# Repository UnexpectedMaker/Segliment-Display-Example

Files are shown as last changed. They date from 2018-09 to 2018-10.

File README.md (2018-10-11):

# Segliment-Display

As promised, I have open sourced my version of the Segliment Display that I made as a joint project with David Watts

The repositry includes thw following folders

EAGLE - All Eagle CAD files (v9.2)

GERBERS - All gerber files

SEGLIMENT_DISPLAY_EXAMPLE - Example Arduino code

Plus there is a PDF Schematic and BOM

Here are some Affiliate & Non-Affiliate links to some of the parts I am using..

COB LED Filaments 

http://s.click.aliexpress.com/e/H0sUjrw

MCP23017SP2 GPIO Port Expander

https://www.aliexpress.com/item/10PCS-MCP23017-E-SP-DIP-28-MCP23017-16-Bit-I-O-Expander-with-I2C-Interface-IC/32866049803.html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

10k Network Resistor

http://s.click.aliexpress.com/e/cFmRmzUk

Enjoy!

# Buy me a coffee or back me on Patreon?
I love making and designing projects but sharing open source projects takes a lot of thought and time. I do it because I think it’s important to share knowledge and give back to the community like many have done before me.

If you find this project useful or want to see more open source projects like it, please consider buying me a coffee or backing me on Patreon to say thanks!

buymeacofee (https://www.buymeacoffee.com/YLVGbhJP0)


# Unexpected Maker
http://youtube.com/c/unexpectedmaker

http://twitter.com/unexpectedmaker

https://www.facebook.com/unexpectedmaker/

https://www.instagram.com/unexpectedmaker/

https://www.tindie.com/stores/seonr/

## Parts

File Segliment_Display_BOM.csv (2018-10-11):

Partlist exported from /Users/seon/Dropbox/EagleCAD/projects/Siglement Display/Siglement 2018-2/Segliment_Display.sch at 11/10/18 4:24 PM
Part   Value       Device                          Package               Description
C1     0.1uF       0.1UF-KIT-EZ-50V-20%            CAP-PTH-SMALL-KIT     0.1µF ceramic capacitors
C2     10uF        10UF-POLAR-RADIAL-2.5MM-25V-20% CPOL-RADIAL-2.5MM-5MM 10.0µF polarized capacitors
IC1    MCP23017SP2 MCP23017SP2                     DIL28-3-ROUND         hMCP23017SP2 GPIO Expander
IO_IN              CONN_041X04_NO_SILK             1X04_NO_SILK          0.254mm 4 pin header
IO_OUT             CONN_041X04_NO_SILK             1X04_NO_SILK          0.254mm 4 pin header
J1                 CONN_031X03_NO_SILK             1X03_NO_SILK        	 0.254mm 3 pin header
J2                 CONN_031X03_NO_SILK             1X03_NO_SILK          0.254mm 3 pin header
J3                 CONN_031X03_NO_SILK             1X03_NO_SILK          0.254mm 3 pin header
LED                LED3MM                          LED_3MM               3mm Yellow LED
LED1   1           LED28-30MMRAISED                RAISED                This is a filament LED
LED2   2           LED28-30MMRAISED                RAISED                This is a filament LED
LED3   3           LED28-30MMRAISED                RAISED                This is a filament LED
LED4   4           LED28-30MMRAISED                RAISED                This is a filament LED
LED5   5           LED28-30MMRAISED                RAISED                This is a filament LED
LED6   6           LED28-30MMRAISED                RAISED                This is a filament LED
LED7   7           LED28-30MMRAISED                RAISED                This is a filament LED
LED8   8           LED28-30MMRAISED                RAISED                This is a filament LED
LED9   9           LED28-30MMRAISED                RAISED                This is a filament LED
LED10  10          LED28-30MMRAISED                RAISED                This is a filament LED
LED11  11          LED28-30MMRAISED                RAISED                This is a filament LED
LED12  12          LED28-30MMRAISED                RAISED                This is a filament LED
LED13  13          LED28-30MMRAISED                RAISED                This is a filament LED
R1                 R-US_0207/7                     0207/7                100R
R2                 R-US_0207/7                     0207/7                100R
R3                 R-US_0207/7                     0207/7                100R
R4                 R-US_0207/7                     0207/7                100R
R5                 R-US_0207/7                     0207/7                100R
R6                 R-US_0207/7                     0207/7                100R
R7                 R-US_0207/7                     0207/7                100R
R8                 R-US_0207/7                     0207/7                100R
R9                 R-US_0207/7                     0207/7                100R
R10                R-US_0207/7                     0207/7                100R
R11                R-US_0207/7                     0207/7                100R
R12                R-US_0207/7                     0207/7                100R
R13                R-US_0207/7                     0207/7                100R
R14                R-US_0207/7                     0207/7                220R
RN                 RN05                            RN-6                  10K RESISTOR NETWORK

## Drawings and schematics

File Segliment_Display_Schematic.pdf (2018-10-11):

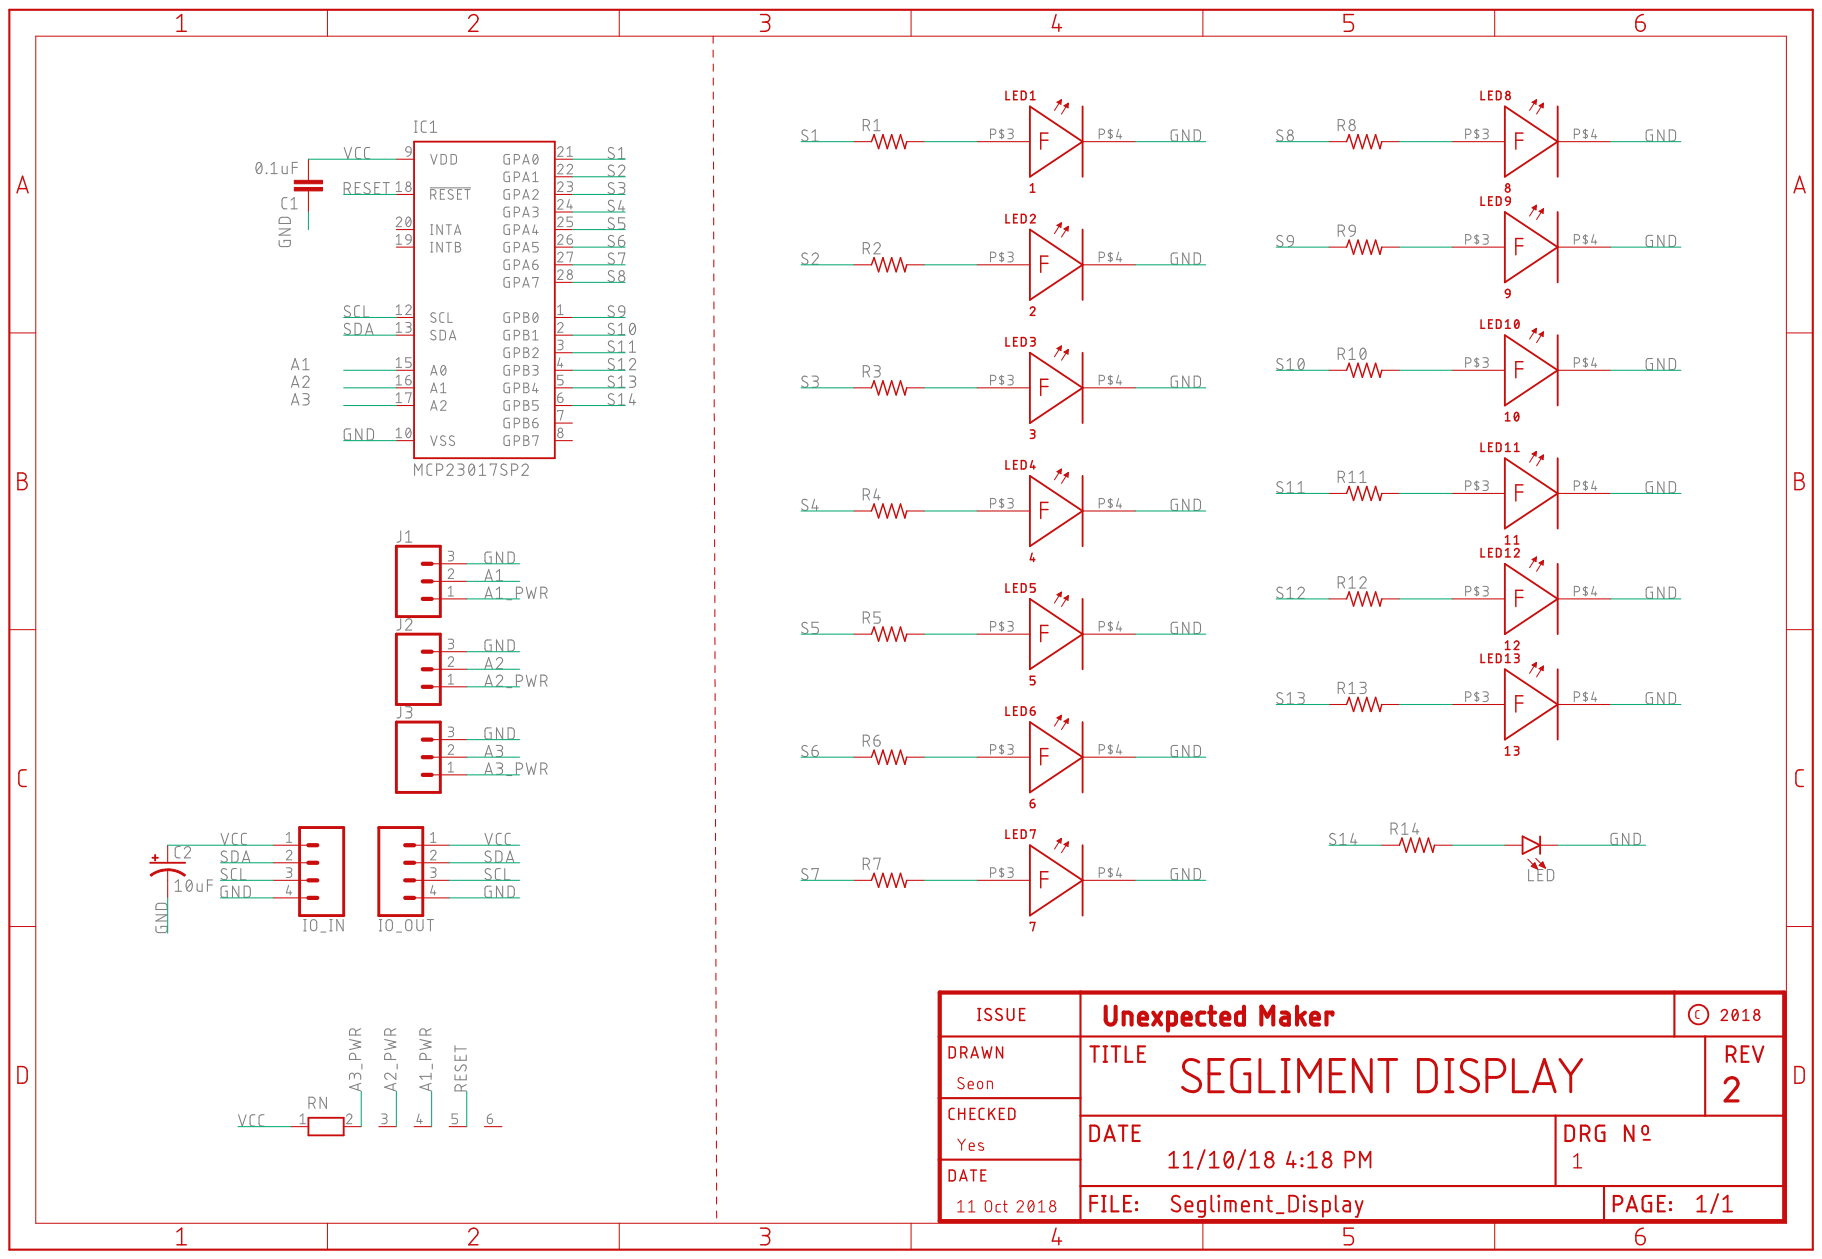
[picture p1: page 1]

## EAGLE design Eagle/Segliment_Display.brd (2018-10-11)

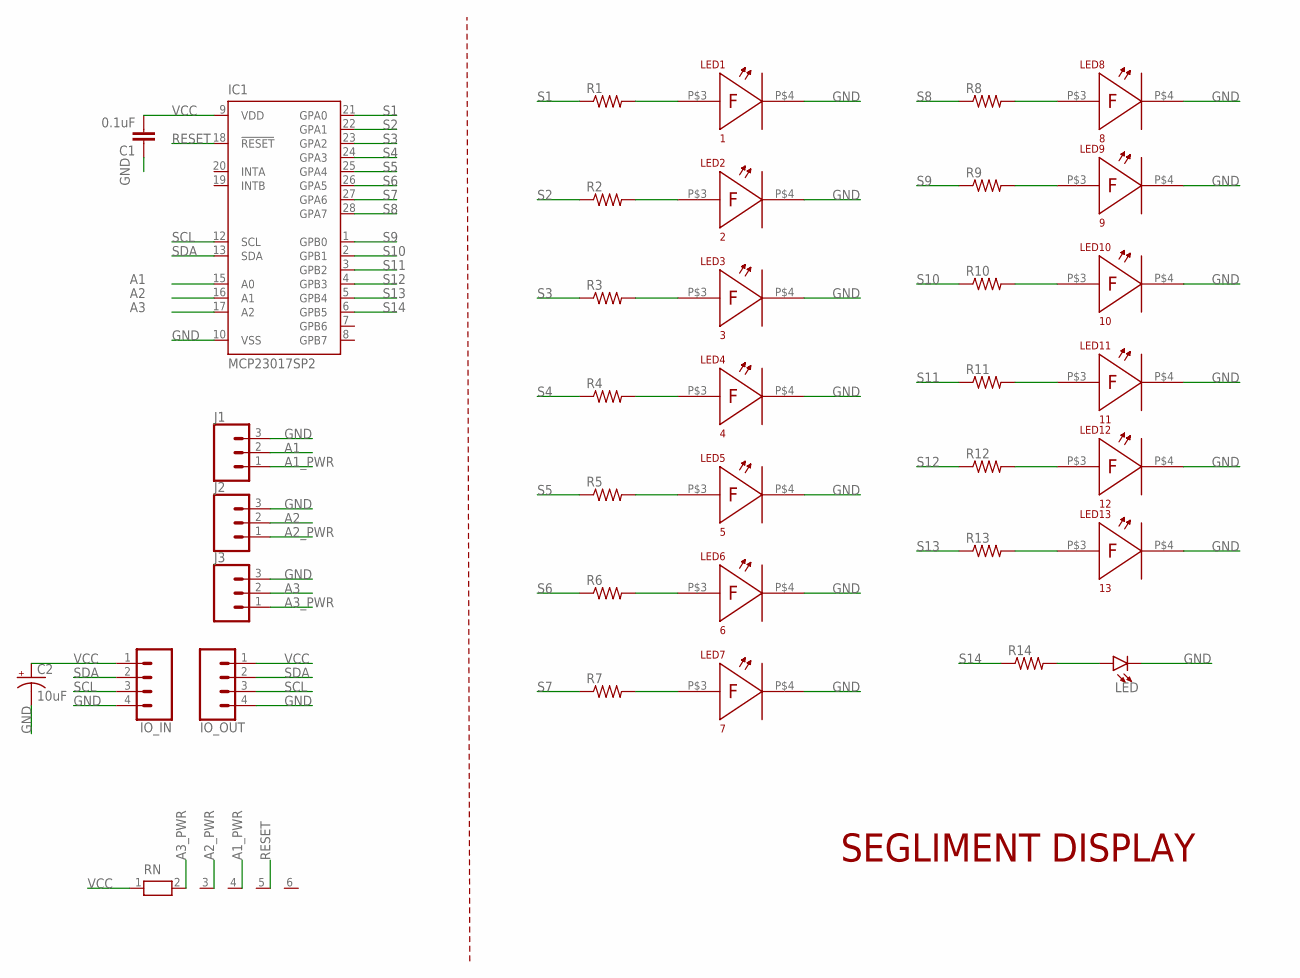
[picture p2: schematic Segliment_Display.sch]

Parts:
C1: 0.1uF; CAP-PTH-SMALL-KIT
C2: 10uF; CPOL-RADIAL-2.5MM-5MM
IC1: MCP23017SP2; DIL28-3-ROUND
IO_IN: CONN_041X04_NO_SILK; 1X04_NO_SILK
IO_OUT: CONN_041X04_NO_SILK; 1X04_NO_SILK
J1, J2, J3: CONN_031X03_NO_SILK; 1X03_NO_SILK
LED: LED3MM; LED_3MM
LED1: 1; RAISED
LED2: 2; RAISED
LED3: 3; RAISED
LED4: 4; RAISED
LED5: 5; RAISED
LED6: 6; RAISED
LED7: 7; RAISED
LED8: 8; RAISED
LED9: 9; RAISED
LED10: 10; RAISED
LED11: 11; RAISED
LED12: 12; RAISED
LED13: 13; RAISED
R1, R2, R3, R4, R5, R6, R7, R8, R9, R10, R11, R12, R13, R14: R-US_0207/7; 0207/7
RN: RN05; RN-6

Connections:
A1: IC1.15 (A0), J1.2
A1_PWR: J1.1, RN.4
A2: IC1.16 (A1), J2.2
A2_PWR: J2.1, RN.3
A3: IC1.17 (A2), J3.2
A3_PWR: J3.1, RN.2
GND: C1.1, C2.2 (-), IC1.10 (VSS), IO_IN.4, IO_OUT.4, J1.3, J2.3, J3.3, LED.K (C), LED1.P$4, LED2.P$4, LED3.P$4, LED4.P$4, LED5.P$4, LED6.P$4, LED7.P$4, LED8.P$4, LED9.P$4, LED10.P$4, LED11.P$4, LED12.P$4, LED13.P$4
unnamed: LED1.P$3, R1.2
unnamed: LED.A, R14.2
unnamed: LED2.P$3, R2.2
unnamed: LED3.P$3, R3.2
unnamed: LED4.P$3, R4.2
unnamed: LED5.P$3, R5.2
unnamed: LED6.P$3, R6.2
unnamed: LED7.P$3, R7.2
unnamed: LED8.P$3, R8.2
unnamed: LED9.P$3, R9.2
unnamed: LED10.P$3, R10.2
unnamed: LED11.P$3, R11.2
unnamed: LED12.P$3, R12.2
unnamed: LED13.P$3, R13.2
RESET: IC1.18 (!RESET), RN.5
S1: IC1.21 (GPA0), R1.1
S2: IC1.22 (GPA1), R2.1
S3: IC1.23 (GPA2), R3.1
S4: IC1.24 (GPA3), R4.1
S5: IC1.25 (GPA4), R5.1
S6: IC1.26 (GPA5), R6.1
S7: IC1.27 (GPA6), R7.1
S8: IC1.28 (GPA7), R8.1
S9: IC1.1 (GPB0), R9.1
S10: IC1.2 (GPB1), R10.1
S11: IC1.3 (GPB2), R11.1
S12: IC1.4 (GPB3), R12.1
S13: IC1.5 (GPB4), R13.1
S14: IC1.6 (GPB5), R14.1
SCL: IC1.12 (SCL), IO_IN.3, IO_OUT.3
SDA: IC1.13 (SDA), IO_IN.2, IO_OUT.2
VCC: C1.2, C2.1 (+), IC1.9 (VDD), IO_IN.1, IO_OUT.1, RN.1

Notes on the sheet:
SEGLIMENT DISPLAY

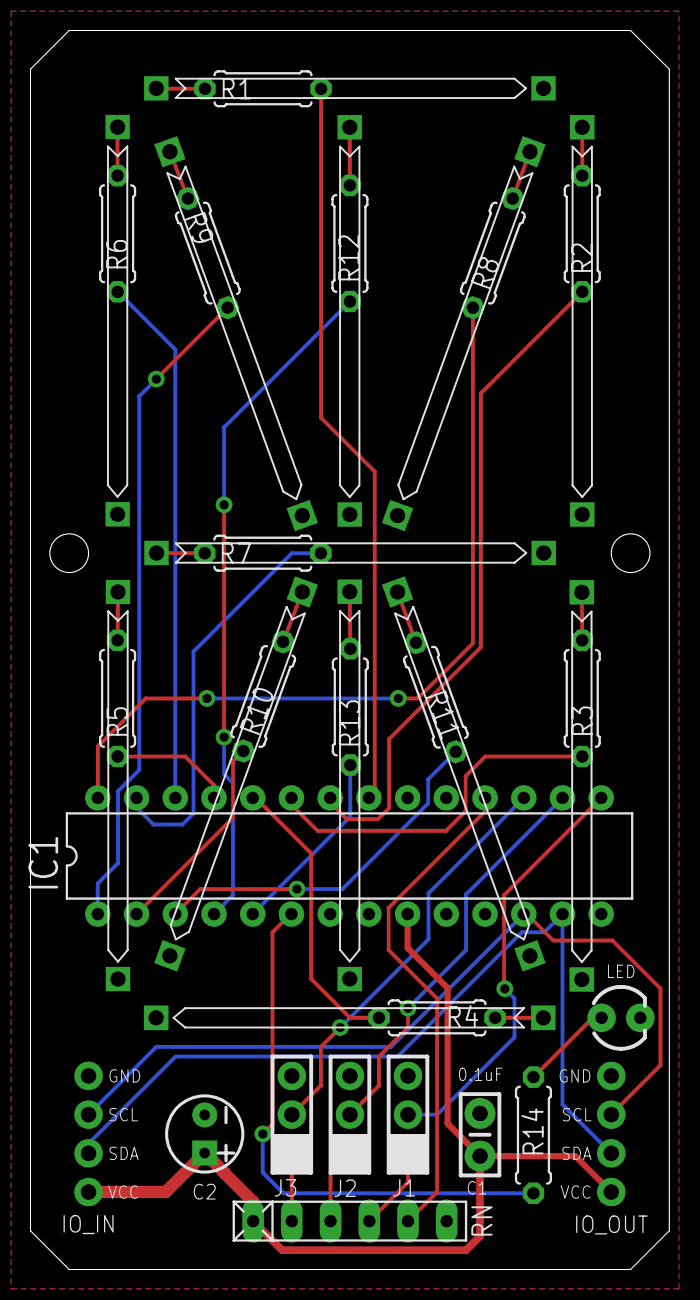
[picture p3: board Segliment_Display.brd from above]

Board: 2 copper layers, 41.9 x 81.3 mm, 37 parts (0 on the bottom side), 39 nets.

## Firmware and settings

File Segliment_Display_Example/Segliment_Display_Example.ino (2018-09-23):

// ---------------------------------------------------------------------------
// Created by Seon Rozenblum - seon@unexpectedmaker.com
// Copyright 2018 License: GNU GPL v3 http://www.gnu.org/licenses/gpl-3.0.html
//
// Required libraries
// Adafruit_MCP23017
// ---------------------------------------------------------------------------

#include <Wire.h>
#include "Adafruit_MCP23017.h"

typedef struct 
{
  char id;
  uint16_t leds;
} CharacterX;

// Available characters the segliment display can show            
const byte ARRAY_SIZE = 49;

CharacterX characters_led[ ARRAY_SIZE ] {
  { ' ', 0b0000000000000000 },
  { '0', 0b0000000000111111 }, 
  { '1', 0b0000000010000110 },
  { '2', 0b0000000001011011 },
  { '3', 0b0000000001001111 },
  { '4', 0b0000000001100110 },
  { '5', 0b0000000001101101 },
  { '6', 0b0000000001111100 },
  { '7', 0b0001000010000001 },
  { '8', 0b0000000001111111 },
  { '9', 0b0000000001100111 },
  { 'a', 0b0000000001110111 },
  { 'b', 0b0001100001001111 },
  { 'c', 0b0000000000111001 },
  { 'd', 0b0001100000001111 },
  { 'e', 0b0000000001111001 },
  { 'f', 0b0000000001110001 },
  { 'g', 0b0000010000111001 },
  { 'h', 0b0000000001110110 },
  { 'i', 0b0001100000001001 },
  { 'j', 0b0000000000011110 },
  {'k', 0b0000010010110000 },
  {'l', 0b0000000000111000},
  {'m', 0b0000000110110110},
  {'n', 0b0000010100110110},
  {'o', 0b0000000000111111},
  {'p', 0b0000000001110011},
  {'q', 0b0000010000111111},
  {'r', 0b0000010010110001},
  {'s', 0b0000000101001101},
  {'t', 0b0001100000000001},
  {'u', 0b0000000000111110},
  {'v', 0b0000001010110000},
  {'w', 0b0000011000110110},
  {'x', 0b0000011110000000},
  {'y', 0b0001000110000000},
  {'z', 0b0000001010001001},
  {'*', 0b0001111110000000},
  {'+', 0b0001100001000000},
  {'-', 0b0000000001000000},
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
};

// Create a reference for each display
Adafruit_MCP23017 mcp[1];
  
void setup()
{ 
  // Initialise each display with it's I2C address
  mcp[0].begin(1);      

  // Set each IO on the display to be outputs
  for ( int i = 0; i < 15; i++ )
    mcp[0].pinMode(i, OUTPUT);

  // clear the display
  ClearDisplay(0);

  // show some characters
  ShowCharacter( 0, 'h' );
  delay(500);
  ShowCharacter( 0, 'e' );
  delay(500);
  ShowCharacter( 0, 'l' );
  delay(500);
  ShowCharacter( 0, 'l' );
  delay(500);
  ShowCharacter( 0, 'o' );
  delay(500);

  // clear the display
  ClearDisplay(0);
}

// show a character on a display
void ShowCharacter( byte disp, byte c )
{
  ShowBytes( 0, FindCharacterX( c ).leds );
}

// set bytes directly on a display
void ShowBytes( byte disp, uint16_t bytes )
{
  for (int i = 0; i < 15; i++ )
  {
    mcp[disp].digitalWrite(i, ( bitRead( bytes, i) == 1 ) ? HIGH : LOW );
  }
}

// clear the display
void ClearDisplay( byte disp )
{
  for ( int i = 0; i < 15; i++ )
  {
    mcp[disp].digitalWrite(i, LOW);
  }
}

void loop() 
{

  // go through every character in the array and show it on display 0
  for ( int i = 0; i < ARRAY_SIZE; i++ )
  {
      ShowBytes( 0, characters_led[i].leds );
      delay(500);
  }
}

// find the bytes for a character in the array
CharacterX FindCharacterX( byte c )
{
  for ( int i = 0; i < ARRAY_SIZE; i++ )
  {
    if ( characters_led[i].id == c )
      return characters_led[i];
  }

  return characters_led[0];
}

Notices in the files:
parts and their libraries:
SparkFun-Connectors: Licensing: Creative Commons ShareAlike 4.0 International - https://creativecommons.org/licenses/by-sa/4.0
